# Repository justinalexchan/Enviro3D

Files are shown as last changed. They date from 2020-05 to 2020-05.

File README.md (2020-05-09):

# Enviro3D
A 3D environment scanner built using the MSP432E401Y microcontroller. The scanner will take distance measurements of a given environment and create a point cloud for 3D modeling.

________________

## General Description: 

The Enviro3D is a 3D Scanner that utilizes a ToF sensor and other components to accurately create a 3D mapping of a given environment. The processes of generating a 3D render from start to finish can be grouped into three main sections: Data Acquisition, Data Processing, and Data Visualization.

During data acquisition, the device uses it’s ToF sensor to collect distance measurement of the environment. The ToF sensor uses a 940 nm invisible laser and calculates the distance of a surface based on the time taken for the beam of light to reflect and return to the sensor. Once this data is collected, it is sent to the computer via serial I2C protocol in which it is received by a python program that is capable of receiving serial data. The python is then parsed and stored for processing. This Repeats until the stepper motor the ToF is mounted on completes a 360 degree rotation to ensure that enough distance data points are gathered. 

During data processing and data visualization, the distance data received is converted into XYZ coordinates which are then stored in a XYZ file and imported in a 3D processing program to generate a 3D visualization. These processes will be analyzed in detail in the coming sections. 

### Device Overview:
  
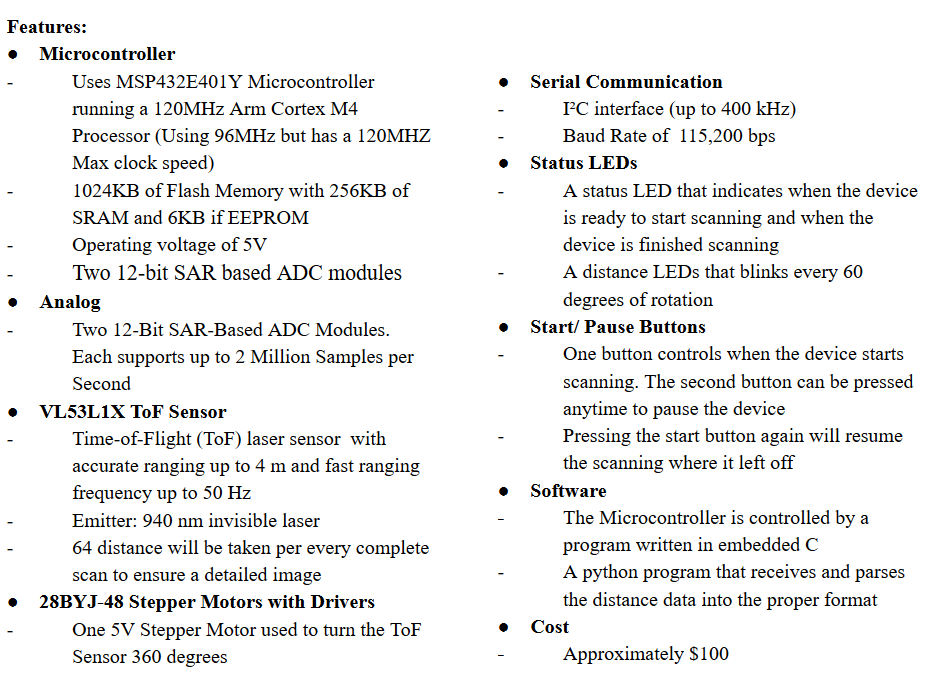
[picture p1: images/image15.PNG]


### Block Diagram (Data flow graph):
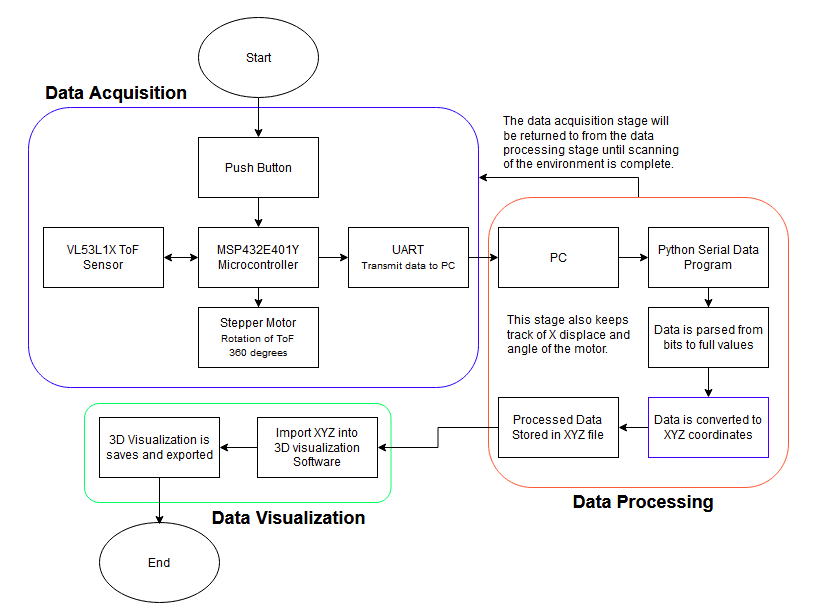
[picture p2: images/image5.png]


### Device Characteristics:
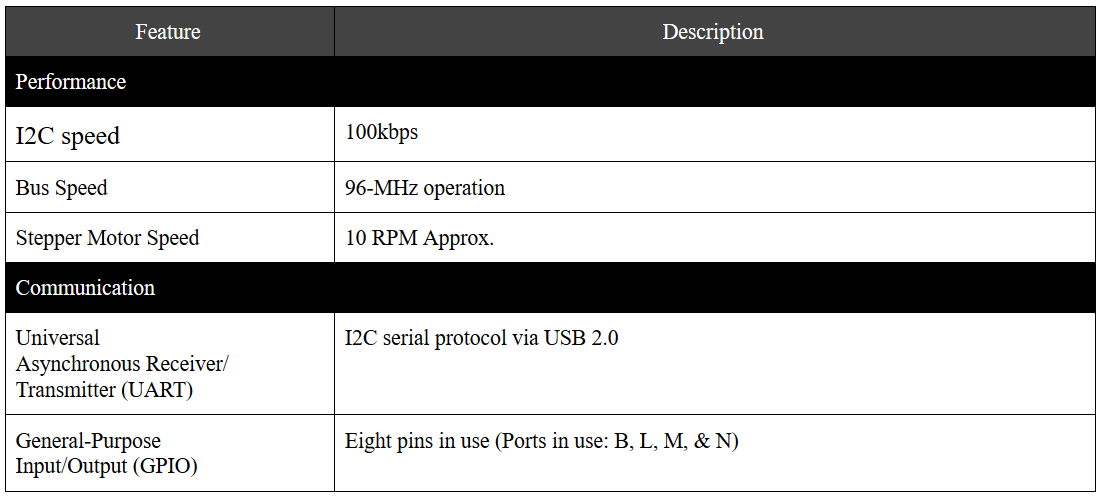
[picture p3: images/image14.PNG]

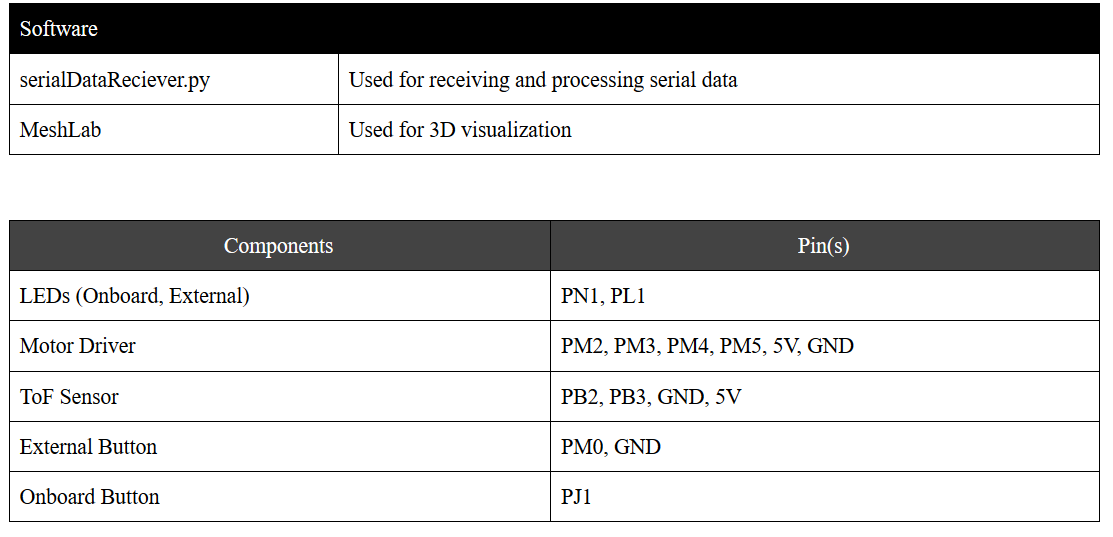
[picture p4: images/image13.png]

### Detailed Description:
#### Distance Measurement:
A key component of measuring distances was the VL53L1X ToF Sensor. The VL53L1X uses a VCSEL (Vertical Cavity Surface Emitting Laser) to emit a 940 nm Infrared laser to time the reflection to the target. Although it’s distance is limited to 4 meters, it can actually measure distances with millimeter accuracy. (Distances are measured in mm)  
The following is the wiring diagram to connect the VL53L1X to the microcontroller. Only the SDA and SCL wires carry data. Looking at the circuit schematic (Figure 1), a better view of how the VL53L1X is connected with respect to other components of the system. 

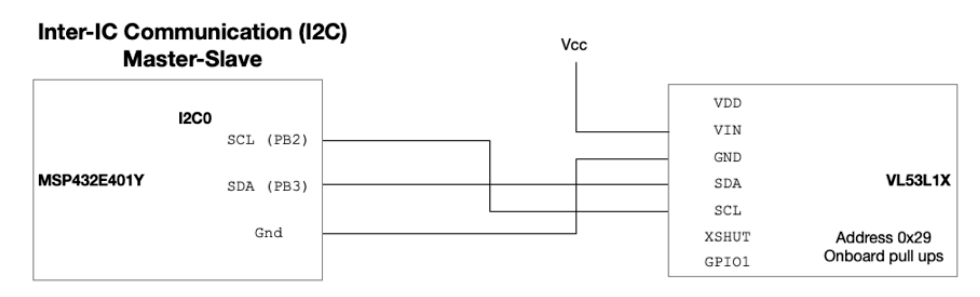
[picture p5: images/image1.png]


VL53L1X Wiring Diagram. 2020. 

#### Communication:
The VL53L1X uses I2C interface to communicate with other devices. To use the I2C interface, the SDA and SCL pins have to be wired to GPIO pins on the microcontroller. Note the SDA pin is used for data transmitting (Digital input/output) while the SCL pin is only used as serial clock input (Digital input). 

Note communication between devices is done through the Universal Asynchronous Receiver/
Transmitter (UART) which must first be initialized via code. 

#### Data Acquisition and Transmission Process:
The following is a brief flowchart of the process:
Logo Title Text 1

The VL53L1X must first be initialized to begin its measurements. Initialization all happens within the code and includes processes like booting the ToF chip, clearing interrupts, setting up default settings and enabling ranging. The following step is to start the measurement and to wait for the data to be ready before. Once the data is ready, it is sent to the microcontroller which then sends it to a PC. This is done with the help of various UART circuits built into the microcontroller.

Once the process above is finished, the microcontroller tells the stepper motor to rotate by a set amount and the process repeats until the stepper motor is rotated 360 degrees.  The programming logic flowchart (Figure 2) shows how the logic of the process works from start to finish.

#### Conversion to the XYZ Plane:
Logo Title Text 1

Once data is sent from the microcontroller to the PC, a Python program receives it and starts parsing the data. 

#### About the Python program:
The program is written to do four things:
1. Receive serial data
2. Parse bits into distance data
3. Convert distance data to XYZ coordinates
4. Output XYZ coordinates to an XYZ file
The program utilizes various python libraries to accomplish these tasks, the most notable being the PySerial and Math libraries. PySerial is used to complete the task of receiving serial data. The incoming data is received in single bits and therefore must be separated by the new line ”\n”. This data is then stored in an array and converted into XYZ coordinates. This is done using the following equations:

#### Equations:
X = X

Y = sin(θ) * distance

Z = cos(θ) * distance
	
Note: The value of X is predetermined and increments accordingly while the value of θ is determined based on the turning angle of the motor and will also increment according (512 steps = 360 degrees, 8/512 steps  * 360 = 5.625 per motor turn)

#### Displacement Measurement:
In this system, displacement starts at zero and incremented by a predetermined value. For testing, the value of 100 (mm) was used. The value is recorded in the python program and will automatically increment after a full rotation has been completed by the stepper motor. 

The MPU-9250  IMU sensor can be implemented similarly to how the ToF sensor was implemented. The code would simply require various new methods to initialize, boot the sensor, and get various acceleration measurements. The device will have to be programmed to start taking measurements one stepper stops moving and stops when the motor starts moving again. The measured data can then be sent to a PC and parsed accordingly. (Note: The MPU-9250 has SDA and SCL pins which makes the wiring very similar to the ToF sensor).

Knowing that displacement is the double integral of acceleration, the x-displacement data can be calculated using the acceleration measurements taken by the IMU and by counting the total amount of measurements taken (which can be used to determine the total time by multiplying it with the frequency of measurements taken). 

#### Visualization:
Two methods of visualization were used in testing:
1. Using Open3D to plot the 3D contours based on the point cloud
2. Using MeshLab to construct a surface based on the point cloud generated 

Both of these methods were used on a computer with the following specs:
-        Processor: Intel i5 3.3GHz
-        Graphics: Intel HD620
-        Memory: 8GB
-        Storage: 256GB SSD
-        OS: Windows 10

The first step to visualize the scanned environment is generating a point cloud from the XYZ coordinates created during the data conversion process (refer to programming logic flowchart for a better idea). A simple way to do this is to store the XYZ coordinates in an XYZ file which can then be imported into programs for 3D processing. 

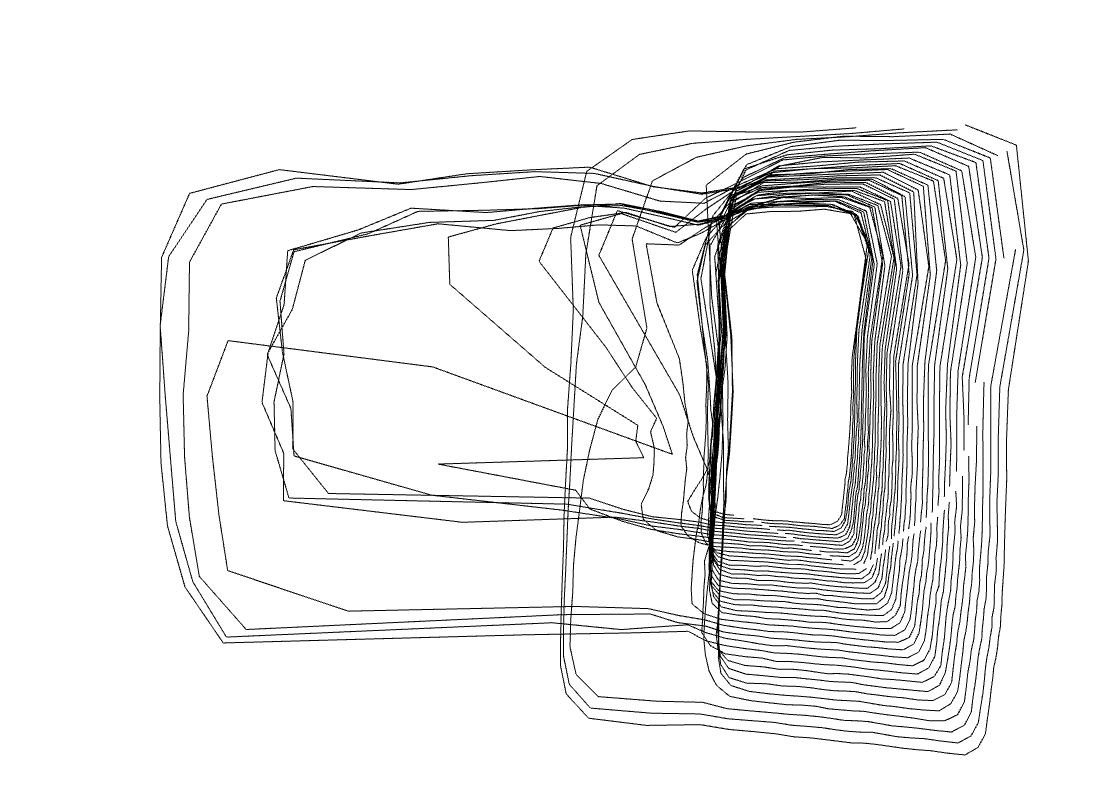
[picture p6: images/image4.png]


The first method of visualization uses a python library called Open3D. Open3D is an open sourced library that allows for the processing of 3D data. Using this library, the program can read the points stored in a given XYZ file and display it as a 3D model. Lines can also be generated that connect the various points to generate a 3D contour model of the scanned environment.  
*Note: Additional libraries can be imported such as trimesh which utilizes a ball pivoting algorithm to generate surfaces that can also be used to create more realistic looking models.

An issue with using the Open3D library is that it requires a lot of graphic processing power. Without a dedicated GPU rendering will often crash or not generate a 3D visualization at all.
  
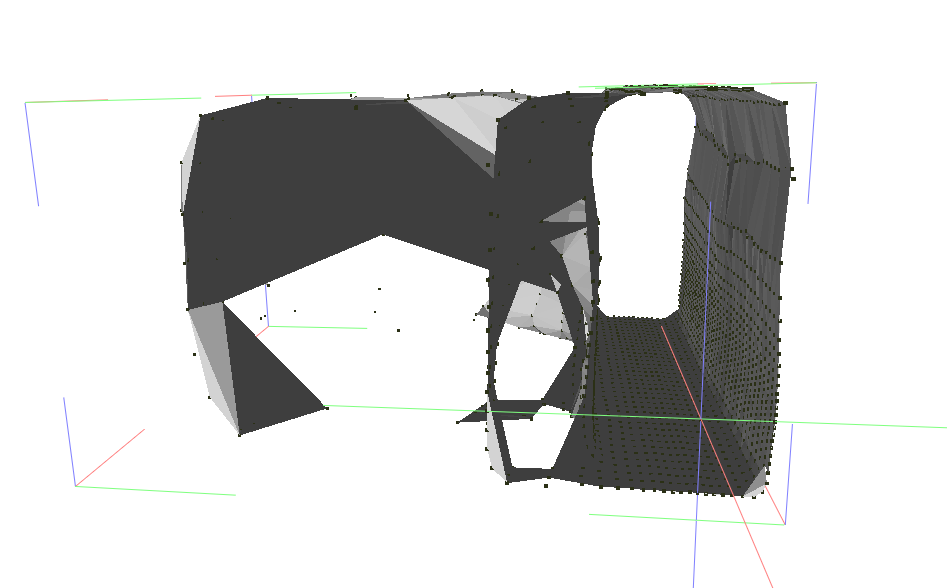
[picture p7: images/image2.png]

Method two solves that issue by providing a more optimized program that can perform 3D renders with less graphic processing power. MeshLab is a mesh processing software that can generate detailed meshes from point clouds. By importing the XYZ file into the programming and using various tools like Poisson Surface Reconstruction and Ball Pivoting Surface reconstruction, detailed 3D renderings can be generated which can also be exported as STL files. 

#### Application:
An application of this device is using it to map the internal structure of a building. The following will be an example usage of the device in mapping a hallway inside a house. 
  
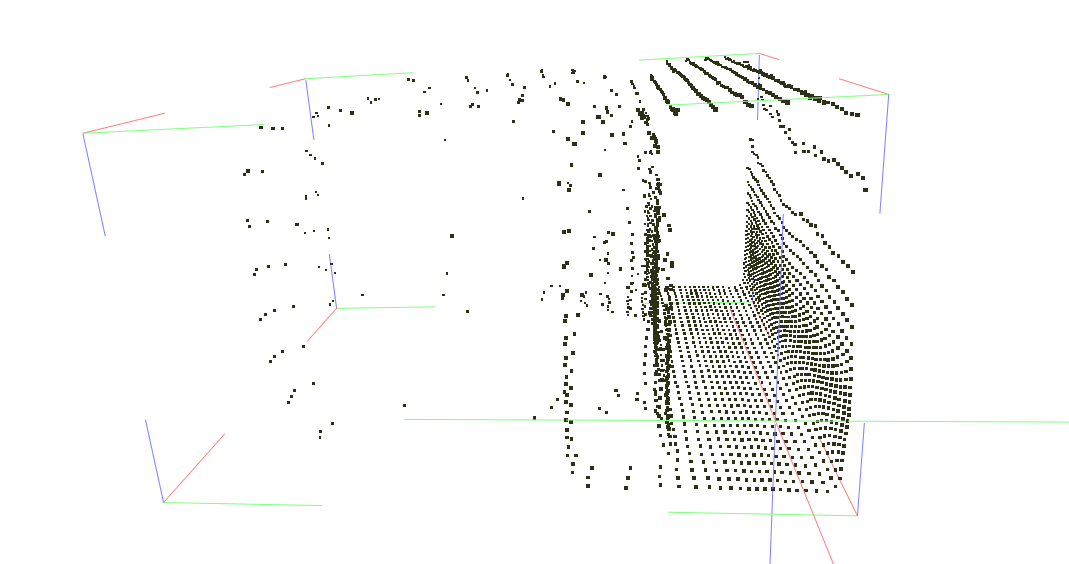
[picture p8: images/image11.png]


Images (1) point cloud of hallway (2) 3D render based on point cloud (3) birds eye view of 3D render

The following scan was created by taking 39 x-axis slices that were 10cm apart. The first image shows the point cloud generated by the python program while the second and third image shows different views of the 3D rendered model. Note that the two pieces extruding from the hallway are rooms with open doors.

Setup:
Follow the wiring schematic (Figure 1) to connect the various components together. When the device is assembled, ensure that 2DX4FinalProject.uvprojx is flashed onto the microcontroller. 

The following is steps to setup the software for data collection:
1. Ensure that the microcontroller is connected to a computer via USB
2. Open and run serialDataReciever.py (You must have python 3 installed)
3. Pressed the red Button connected to the microcontroller to begin scanning
4. Wait until scanning is finished
5. Repeat steps 3 and 4 until the environment is scanned

The XYZ coordinates data will be saved in an XYZ file named “coordinates3D.xyz” in the same directory as the python program.  The data can be imported into Meshlab in which a 3D model can be generated by going to: Filters > Remeshing,Simplification and Reconstruction > Surface Reconstruction: Ball Pivoting > Apply.

*Note: The XYZ planes are defined as:
* X → Forward movement
* Y  and Z → Vertical Plane Slice
The program utilizes serial communication with the following settings:
* COM port → COM3
* Baud Rate → 115200 BPS

#### Circuit Schematic:
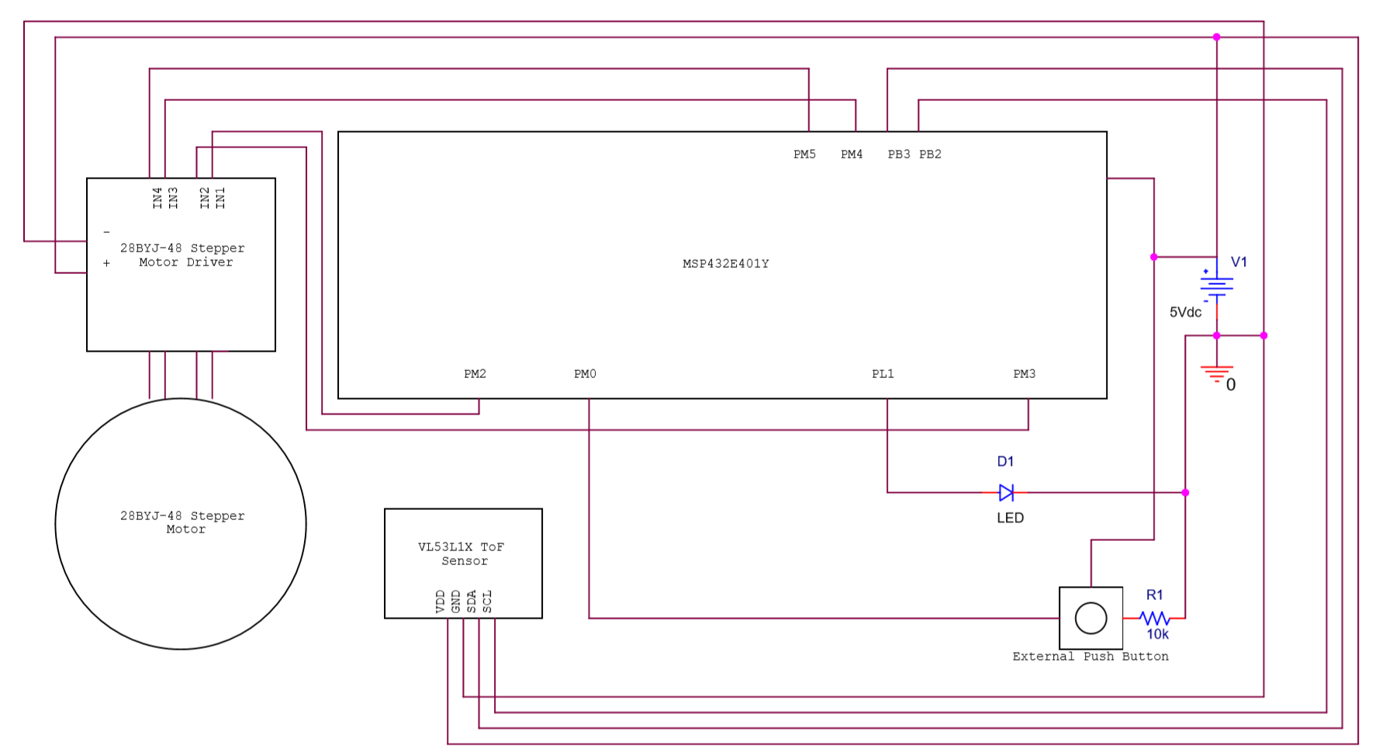
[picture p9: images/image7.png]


Figure 1
________________
#### Programming Logic:
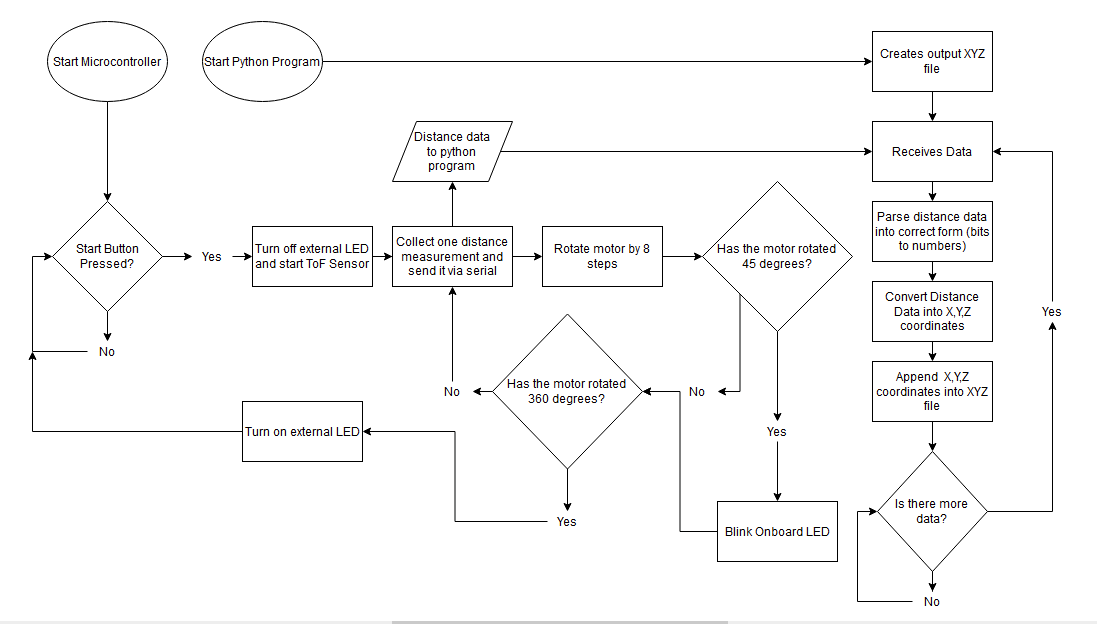
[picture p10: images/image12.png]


Figure 2

________________

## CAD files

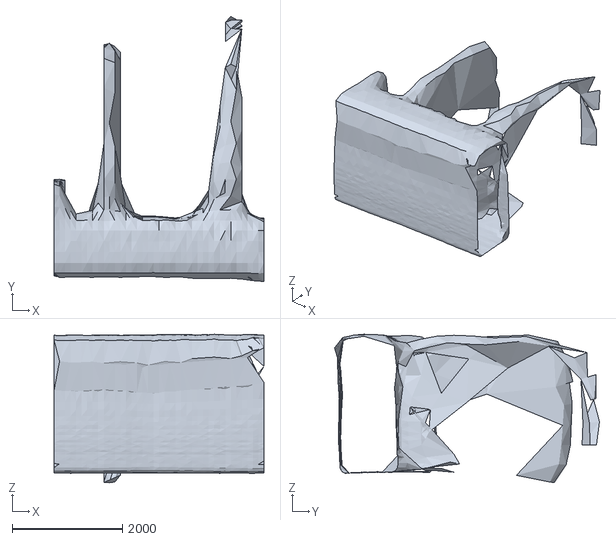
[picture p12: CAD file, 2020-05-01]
dataProcessing/coordinates3D.stl
3800.0 x 4797.0 x 2689.0

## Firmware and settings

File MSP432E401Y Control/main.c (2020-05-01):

//Justin Chan
#include <stdint.h>
#include "tm4c1294ncpdt.h"
#include "vl53l1x_api.h"
#include "PLL.h"
#include "SysTick.h"
#include "uart.h"
#include "onboardLEDs.h"
#include <stdio.h>
#include <stdlib.h>

uint16_t	dev=0x52;

int status=0;

volatile int IntCount;

//device in interrupt mode (GPIO1 pin signal)
#define isInterrupt 1 /* If isInterrupt = 1 then device working in interrupt mode, else device working in polling mode */

void I2C_Init(void);
void UART_Init(void);
void PortG_Init(void);
void VL53L1X_XSHUT(void);

void PortN_Init(void);
void PortL_Init(void);
void PortM_Init(void);
void motorStart(void);
//capture values from VL53L1X for inspection
uint16_t debugArray[100];



//Interupt

// Enable interrupts
void EnableInt(void)
{    __asm("    cpsie   i\n");
}

// Disable interrupts
void DisableInt(void)
{    __asm("    cpsid   i\n");
}


// global variable visible in Watch window of debugger
// increments at least once per button press
// GPIO Port J = Vector 67
// Bit in interrupt register = 51

void ExternalButton_Init(void){
	SYSCTL_RCGCGPIO_R |= SYSCTL_RCGCGPIO_R8;				// activate clock for Port J
	while((SYSCTL_PRGPIO_R&SYSCTL_PRGPIO_R8) == 0){};	// allow time for clock to stabilize

  GPIO_PORTJ_DIR_R &= ~0x02;    // (c) make PJ1 in 

  GPIO_PORTJ_DEN_R |= 0x02;     //     enable digital I/O on PJ1
	GPIO_PORTJ_PCTL_R &= ~0x000000F0; //� configure PJ1 as GPIO 
	GPIO_PORTJ_AMSEL_R &= ~0x02;	//�� disable analog functionality on PJ1		
	GPIO_PORTJ_PUR_R |= 0x02;			//	enable weak pull up resistor
  GPIO_PORTJ_IS_R &= ~0x02;     // (d) PJ1 is edge-sensitive 
  GPIO_PORTJ_IBE_R &= ~0x02;    //     PJ1 is not both edges 
  GPIO_PORTJ_IEV_R &= ~0x02;    //     PJ1 falling edge event 
  GPIO_PORTJ_ICR_R = 0x02;      // (e) clear flag1
  GPIO_PORTJ_IM_R |= 0x02;      // (f) arm interrupt on PJ1
  NVIC_PRI13_R = (NVIC_PRI13_R&0xFF00FFFF)|0x000A0000; // (g) priority 5
  NVIC_EN1_R |= 0x00080000;              // (h) enable interrupt 67 in NVIC
  EnableInt();           				// lets go
}

void GPIOJ_IRQHandler(void){
	GPIO_PORTJ_ICR_R = 0x02;      // acknowledge flag
	SysTick_Wait(1200000);

	while((GPIO_PORTM_DATA_R&0b00000001)== 0){
		
	}
}

int main(void) {
  uint8_t byteData, sensorState=0, myByteArray[10] = {0xFF, 0xFF, 0xFF, 0xFF, 0xFF, 0xFF, 0xFF, 0xFF, 0xFF, 0xFF} , i=0;
  uint16_t wordData;
  uint8_t ToFSensor = 1; // 0=Left, 1=Center(default), 2=Right
  uint16_t Distance;
  uint16_t SignalRate;
  uint16_t AmbientRate;
  uint16_t SpadNum; 
  uint8_t RangeStatus;
  uint8_t dataReady;

	//initialize
	PLL_Init();	
	SysTick_Init();
	onboardLEDs_Init();
	I2C_Init();
	UART_Init();
	
	PortM_Init();
	PortL_Init();
	
	ExternalButton_Init();
	// hello world!
	UART_printf("Program Begins\r\n");
	int mynumber = 1;
	sprintf(printf_buffer,"2DX4 Final Project Code \r\n");
	UART_printf(printf_buffer);


/* Those basic I2C read functions can be used to check your own I2C functions */
  status = VL53L1_RdByte(dev, 0x010F, &byteData);					// This is the model ID.  Expected returned value is 0xEA
  myByteArray[i++] = byteData;

  status = VL53L1_RdByte(dev, 0x0110, &byteData);					// This is the module type.  Expected returned value is 0xCC
  myByteArray[i++] = byteData;
	
	status = VL53L1_RdWord(dev, 0x010F, &wordData);
	status = VL53L1X_GetSensorId(dev, &wordData);

	sprintf(printf_buffer,"Model_ID=0x%x , Module_Type=0x%x\r\n",myByteArray[0],myByteArray[1]);
	UART_printf(printf_buffer);

	// Booting ToF chip
	while(sensorState==0){
		status = VL53L1X_BootState(dev, &sensorState);
		SysTick_Wait10ms(10);
  }
	FlashAllLEDs();
	UART_printf("ToF Chip Booted!\r\n");
 	UART_printf("One moment...\r\n");
	
	status = VL53L1X_ClearInterrupt(dev); /* clear interrupt has to be called to enable next interrupt*/

	
  /* This function must to be called to initialize the sensor with the default setting  */
  status = VL53L1X_SensorInit(dev);
	Status_Check("SensorInit", status);

  status = VL53L1X_StartRanging(dev);   /* This function has to be called to enable the ranging */
	Status_Check("StartRanging", status);

	UART_printf("Push Button to begin...\r\n");
	int aglCount = 0;
	while(1){
		aglCount = 0;
		GPIO_PORTL_DATA_R |= 0b00010;
		if(((GPIO_PORTM_DATA_R&0b00000001)== 1)){	//Detects if button is pushed
			GPIO_PORTL_DATA_R = 0b00000;
			for(int i = 0; i < 64; i++) {	//Takes 64 Distance measurement
				while (dataReady == 0){
					status = VL53L1X_CheckForDataReady(dev, &dataReady);
							//FlashLED3(1);
							VL53L1_WaitMs(dev, 5);
				}

					dataReady = 0;
				status = VL53L1X_GetRangeStatus(dev, &RangeStatus);
				status = VL53L1X_GetDistance(dev, &Distance);
					//FlashLED4(1);

					debugArray[i] = Distance;
				status = VL53L1X_ClearInterrupt(dev); /* clear interrupt has to be called to enable next interrupt*/
					//sprintf(printf_buffer,"%u, %u, %u, %u, %u\r\n", RangeStatus, Distance, SignalRate, AmbientRate,SpadNum);
					sprintf(printf_buffer,"%u\r\n", Distance);	// only prints distance data
					UART_printf(printf_buffer);
				
				motorStart();	//Rotates motor 8 steps
				aglCount += 8;
				if(aglCount % 64 == 0){		//Blinks onboard LED every 45 degrees
					FlashLED1(1);
				}
			}
		}
	}
VL53L1X_StopRanging(dev);

}

//TOF Code
#define I2C_MCS_ACK             0x00000008  // Data Acknowledge Enable
#define I2C_MCS_DATACK          0x00000008  // Acknowledge Data
#define I2C_MCS_ADRACK          0x00000004  // Acknowledge Address
#define I2C_MCS_STOP            0x00000004  // Generate STOP
#define I2C_MCS_START           0x00000002  // Generate START
#define I2C_MCS_ERROR           0x00000002  // Error
#define I2C_MCS_RUN             0x00000001  // I2C Master Enable
#define I2C_MCS_BUSY            0x00000001  // I2C Busy
#define I2C_MCR_MFE             0x00000010  // I2C Master Function Enable

#define MAXRETRIES              5           // number of receive attempts before giving up
void I2C_Init(void){
  SYSCTL_RCGCI2C_R |= SYSCTL_RCGCI2C_R0;           // activate I2C0
  SYSCTL_RCGCGPIO_R |= SYSCTL_RCGCGPIO_R1;          // activate port B
  while((SYSCTL_PRGPIO_R&0x0002) == 0){};// ready?

    GPIO_PORTB_AFSEL_R |= 0x0C;           // 3) enable alt funct on PB2,3       0b00001100
    GPIO_PORTB_ODR_R |= 0x08;             // 4) enable open drain on PB3 only

    GPIO_PORTB_DEN_R |= 0x0C;             // 5) enable digital I/O on PB2,3
//    GPIO_PORTB_AMSEL_R &= ~0x0C;          // 7) disable analog functionality on PB2,3

                                                                                // 6) configure PB2,3 as I2C
//  GPIO_PORTB_PCTL_R = (GPIO_PORTB_PCTL_R&0xFFFF00FF)+0x00003300;
  GPIO_PORTB_PCTL_R = (GPIO_PORTB_PCTL_R&0xFFFF00FF)+0x00002200;    //TED
    I2C0_MCR_R = I2C_MCR_MFE;                      // 9) master function enable
    I2C0_MTPR_R = 0b0000000000000101000000000111011;                                        // 8) configure for 100 kbps clock (added 8 clocks of glitch suppression ~50ns)
    
}

//The VL53L1X needs to be reset using XSHUT.  We will use PG0
void PortG_Init(void){
    //Use PortG0
    SYSCTL_RCGCGPIO_R |= SYSCTL_RCGCGPIO_R6;                // activate clock for Port N
    while((SYSCTL_PRGPIO_R&SYSCTL_PRGPIO_R6) == 0){};    // allow time for clock to stabilize
    GPIO_PORTG_DIR_R &= 0x00;                                        // make PG0 in (HiZ)
  GPIO_PORTG_AFSEL_R &= ~0x01;                                     // disable alt funct on PG0
  GPIO_PORTG_DEN_R |= 0x01;                                        // enable digital I/O on PG0
                                                                                                    // configure PG0 as GPIO
  //GPIO_PORTN_PCTL_R = (GPIO_PORTN_PCTL_R&0xFFFFFF00)+0x00000000;
  GPIO_PORTG_AMSEL_R &= ~0x01;                                     // disable analog functionality on PN0

    return;
}

//XSHUT     This pin is an active-low shutdown input; the board pulls it up to VDD to enable the sensor by default. Driving this pin low puts the sensor into hardware standby. This input is not level-shifted.
void VL53L1X_XSHUT(void){
    GPIO_PORTG_DIR_R |= 0x01;                                        // make PG0 out
    GPIO_PORTG_DATA_R &= 0b11111110;                                 //PG0 = 0
    FlashAllLEDs();
    SysTick_Wait10ms(10);
    GPIO_PORTG_DIR_R &= ~0x01;                                            // make PG0 input (HiZ)
    
}

//Mid Project Code
#define NVIC_ST_CTRL_R          (*((volatile uint32_t *)0xE000E010))
#define NVIC_ST_RELOAD_R        (*((volatile uint32_t *)0xE000E014))
#define NVIC_ST_CURRENT_R       (*((volatile uint32_t *)0xE000E018))
#define NVIC_ST_CTRL_COUNT      0x00010000  // Count flag
#define NVIC_ST_CTRL_CLK_SRC    0x00000004  // Clock Source
#define NVIC_ST_CTRL_INTEN      0x00000002  // Interrupt enable
#define NVIC_ST_CTRL_ENABLE     0x00000001  // Counter mode
#define NVIC_ST_RELOAD_M        0x00FFFFFF  // Counter load value


void PortN_Init(void){
	//Use PortN onboard LED	
	SYSCTL_RCGCGPIO_R |= SYSCTL_RCGCGPIO_R12;				// activate clock for Port N
	while((SYSCTL_PRGPIO_R&SYSCTL_PRGPIO_R12) == 0){};	// allow time for clock to stabilize
	GPIO_PORTN_DIR_R |= 0b01;        								// make PN0 out (PN0 built-in LED1)
  GPIO_PORTN_AFSEL_R &= ~0b01;     								// disable alt funct on PN0
  GPIO_PORTN_DEN_R |= 0b01;        								// enable digital I/O on PN0
																									// configure PN1 as GPIO
  //GPIO_PORTN_PCTL_R = (GPIO_PORTN_PCTL_R&0xFFFFFF0F)+0x00000000;
								// disable analog functionality on PN0		
	return;
}


void PortL_Init(void){
	SYSCTL_RCGCGPIO_R |= SYSCTL_RCGCGPIO_R10;	
	while((SYSCTL_PRGPIO_R&SYSCTL_PRGPIO_R10) == 0){};	
	GPIO_PORTL_DIR_R |= 0b10;        								
  GPIO_PORTL_AFSEL_R &= ~0b10;     								
  GPIO_PORTL_DEN_R |= 0b10;        								    									
	

	return;
}


void PortM_Init(void){
	SYSCTL_RCGCGPIO_R |= SYSCTL_RCGCGPIO_R11;				
	while((SYSCTL_PRGPIO_R&SYSCTL_PRGPIO_R11) == 0){};	
	GPIO_PORTM_DIR_R |= 0x3C; 
  GPIO_PORTM_AFSEL_R &= ~0x3D;     							
  GPIO_PORTM_DEN_R |= 0x3D;        							
	return;
}

void motorStart(void){
	for(int i = 1; i <= 8; i++){		//512 is one full rotation
		int delay = 192000;

		GPIO_PORTM_DATA_R &= 0b00000000;
		GPIO_PORTM_DATA_R |= 0b00100100;
		SysTick_Wait(delay);
		GPIO_PORTM_DATA_R &= 0b00000000;
		GPIO_PORTM_DATA_R |= 0b00110000;
		SysTick_Wait(delay);
		GPIO_PORTM_DATA_R &= 0b00000000;
		GPIO_PORTM_DATA_R |= 0b00011000;
		SysTick_Wait(delay);
		GPIO_PORTM_DATA_R &= 0b00000000;
		GPIO_PORTM_DATA_R |= 0b00001100;
		SysTick_Wait(delay);

	}
}

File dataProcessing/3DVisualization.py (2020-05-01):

#Justin Chan 
import numpy as np
import open3d as o3d
import trimesh
import matplotlib.pyplot as plt
import matplotlib.tri as mtri

# This is the open3D visualization method which creates 3D contours based on the given point cloud. 
# Open3D requires lots of Graphical Processing power so without a GPU, it will crash.
# The alternative, MeshLab, was used instead.

if __name__ == "__main__":

    pcd = o3d.io.read_point_cloud("3d.xyz", format='xyz')
    print(pcd)

    print(np.asarray(pcd.points))
    #o3d.visualization.draw_geometries([pcd])


    pts = []
    x= 0 
    for i in range(2496):
        pts.append(i)

    
    lines = [] # store lines in a list
    count = 0
    # Use loops to connect points on yz plane
    for x in range(39):
        i = x * 63
        
        while i%63 != 0 or count == 0:
            count = 1
            if i%63 == 0:
                lines.append([pts[i], pts[x * 63]])
            else:
                lines.append([pts[i], pts[i+1]])
            i += 1

        count = 0

    
    line_set = o3d.geometry.LineSet(points=o3d.utility.Vector3dVector(np.asarray(pcd.points)), lines=o3d.utility.Vector2iVector(lines))
    
    o3d.visualization.draw_geometries([line_set])
